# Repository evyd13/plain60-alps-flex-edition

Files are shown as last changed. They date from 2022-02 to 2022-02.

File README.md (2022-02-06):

# Plain60 Alps Flex Edition rev2.2

Plain60 Alps Flex Edition PCB
This 60% alps PCB is designed to support as little layouts as possible without limiting usability for most users.

It also features a fuse and an ESD protection chip to protect the MCU and other parts of the PCB.

## Features
- Compatible with QMK Firmware and VIA Configurator (if you flash a VIA compatible .hex file)
- Compatible with most universal 60% cases
- USB type-C
- Optional JST header for connection with daughterboard
- Footprint for optional speaker (AST1109MLTRQ)
- ESD protection and fuse
- No LEDs and no underglow
- Minimal layout support
- ISP header

## Supported layouts
Supported layouts of the Plain60 Alps Flex Edition

## Building
If you feel like building a few of these PCBs yourself, go to the 'Releases' tab and download the latest gerber files. Order those at your favourite PCB manufacturer, get the components needed (see below) and solder them on! A hot air station is not required but a soldering iron is. Flux is recommended.

## Opening the project
To open the files you will need the latest KiCAD stable (at least 6.0.1) version.

## Bill of materials (BOM)
Amount is per PCB, multiply as needed.

| LCSC part # | Description | Value | Package  | Amount |
| --- | --- | ----- | --- | ---:|
| C128353 | Capacitor | 0.1uF | 0805 | 4 |
| C131056 | Capacitor | 4.7uF | 0805 | 1 |
| C215803 | Capacitor | 1uF | 0805 | 1 |
| C109001 | Diode | | 0805 | 65 |
| C261942 | Fuse | | 0805 | 1 |
| C165948 | Connector | | SMD/THT  | 1 |
| C103904 | Resistor | 10K | 0805 | 2 |
| C212411 | Resistor | 5.1K  | 0805 | 2 |
| C325772 | Resistor | 22 | 0805 | 2 |
| C44854 | MCU | 32U4  | QFP-44 | 1 |
| C7519 | ESD chip | | SOT23-6  | 1 |
| C341521 | Resonator | 16MHz | SMD | 1 |
| C92584 | Switch | | SMD | 1 |
| C160404 | Optional JST  | | SMD | 1 |

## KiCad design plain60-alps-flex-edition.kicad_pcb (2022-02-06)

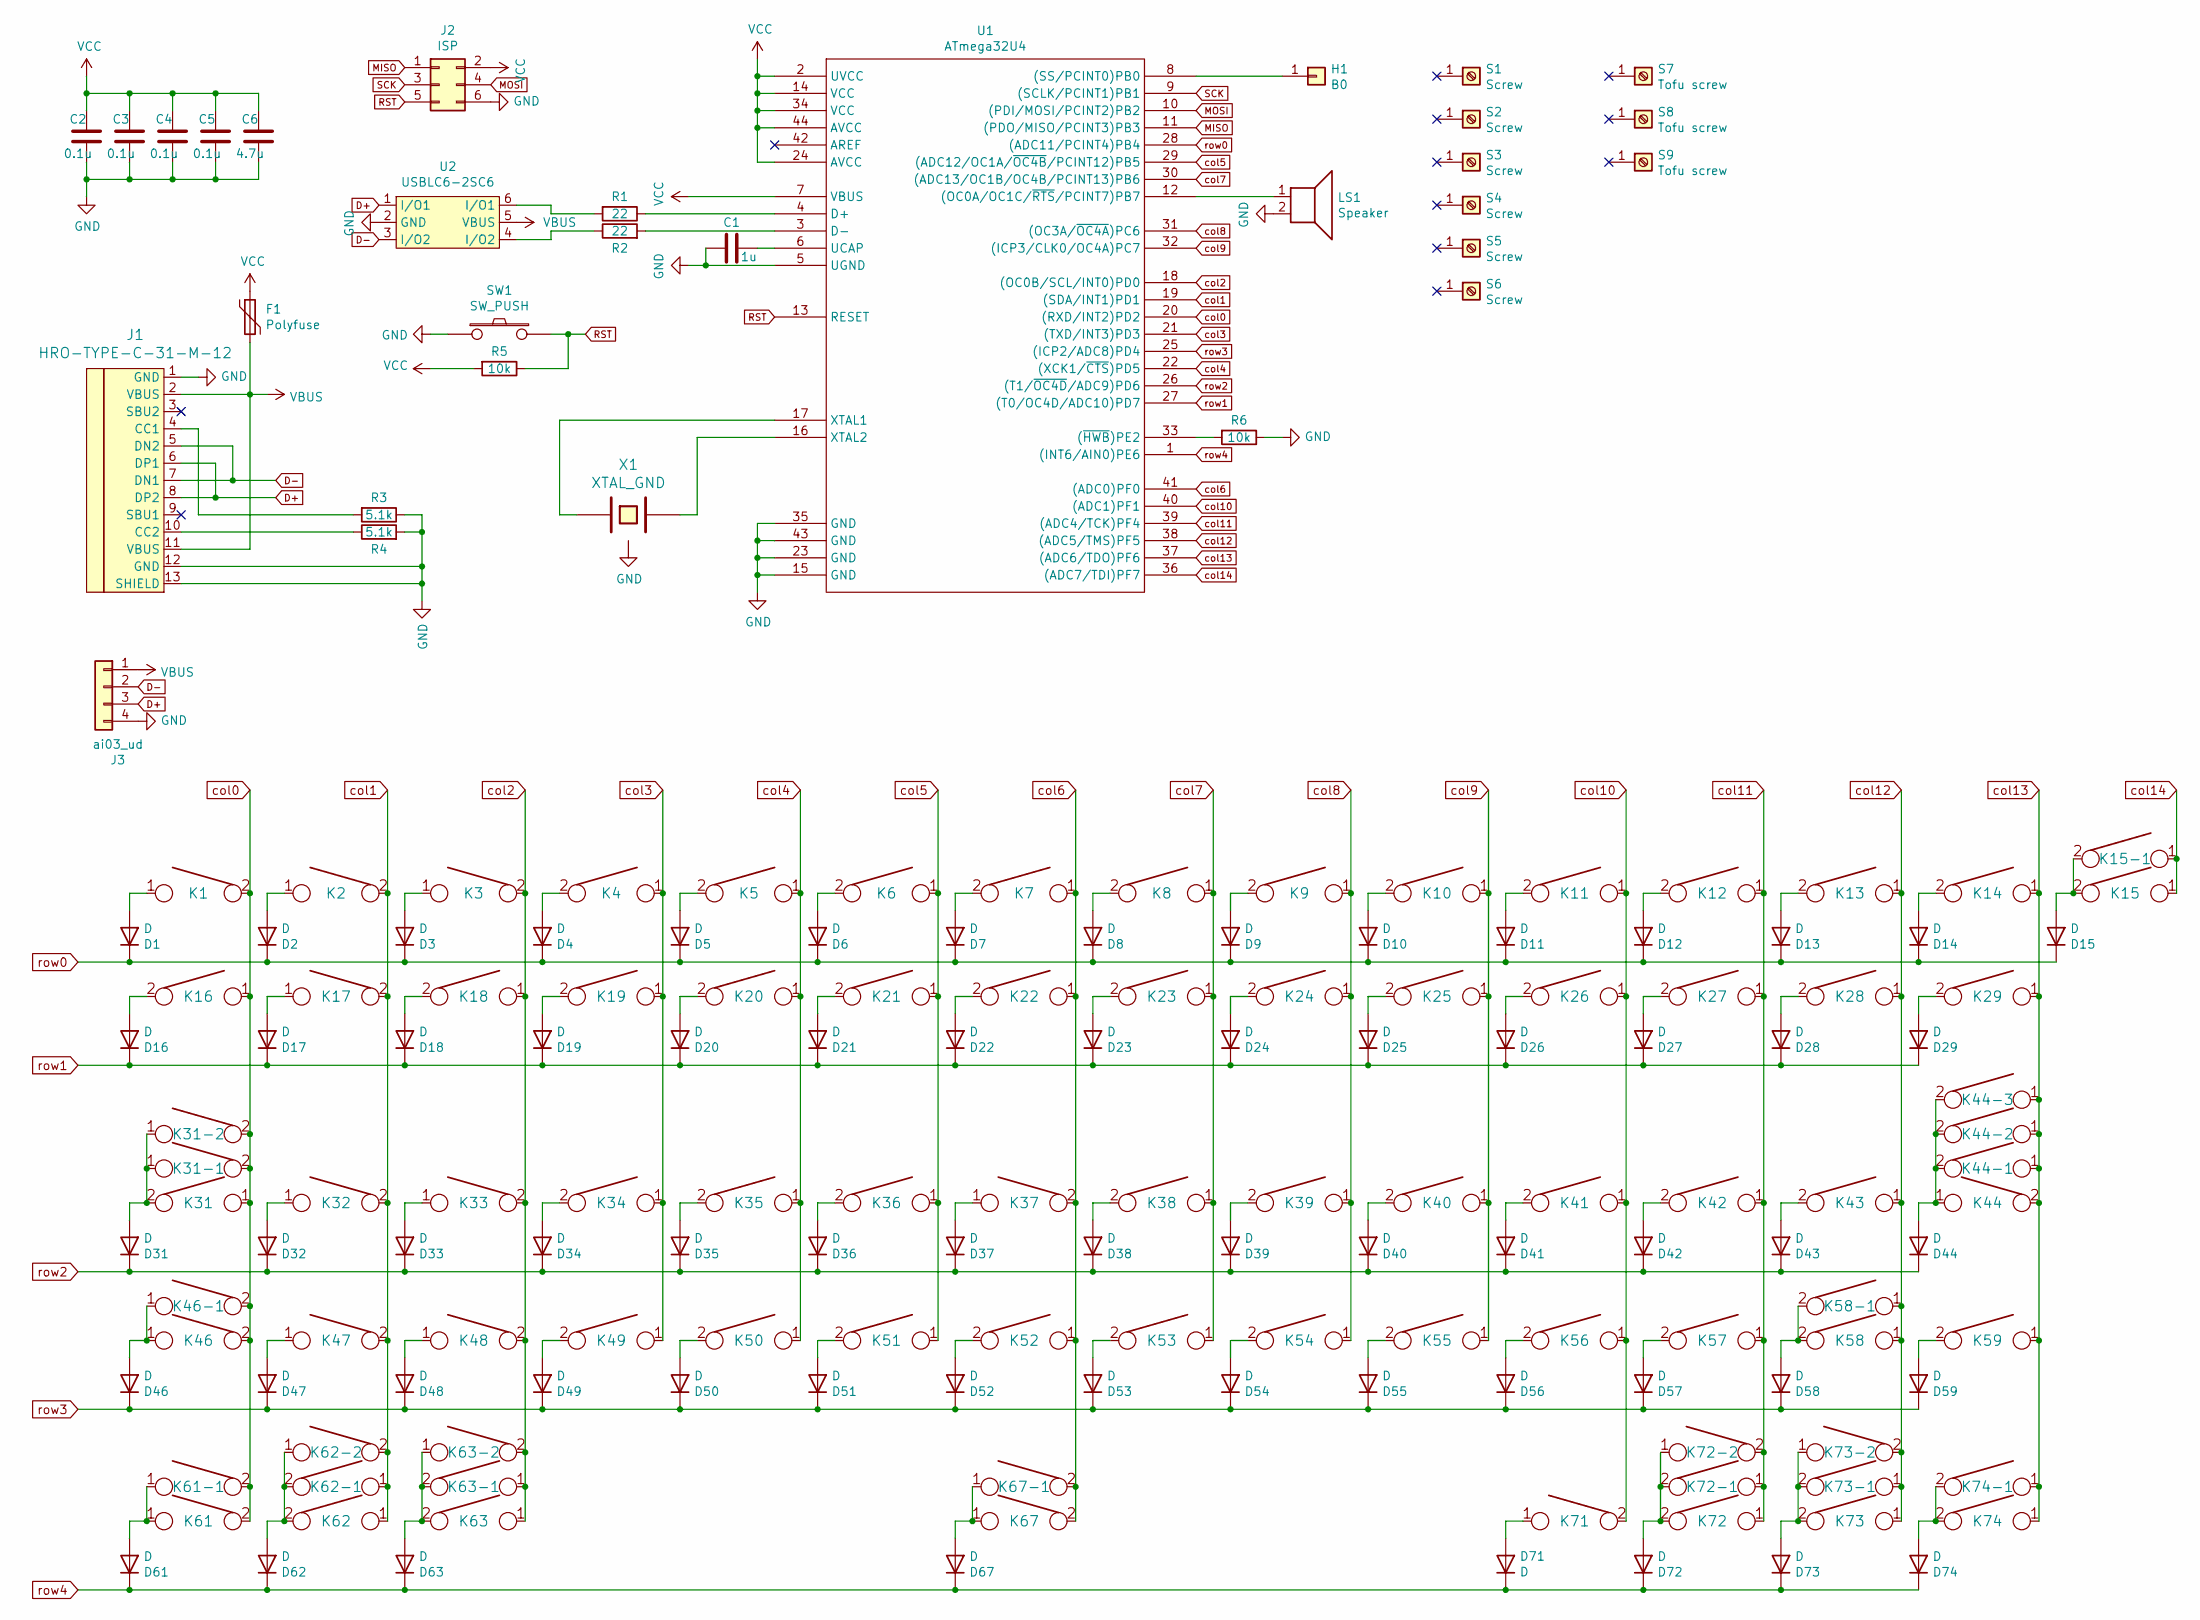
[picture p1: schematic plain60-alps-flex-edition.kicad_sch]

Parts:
C1: 1u; C_0805
C2, C3, C4, C5: 0.1u; C_0805
C6: 4.7u; C_0805
D1, D2, D3, D4, D5, D6, D7, D8, D9, D10, D11, D12, D13, D14, D15, D16, D17, D18, D19, D20, D21, D22, D23, D24, D25, D26, D27, D28, D29, D31, D32, D33, D34, D35, D36, D37, D38, D39, D40, D41, D42, D43, D44, D46, D47, D48, D49, D50, D51, D52, D53, D54, D55, D56, D57, D58, D59, D61, D62, D63, D67, D71, D72, D73, D74: D; D_0805
F1: Polyfuse; R_0805
H1: B0; free_pin
J1: HRO-TYPE-C-31-M-12
J2: ISP; isp_standard
J3: ai03_ud; JST_SH_SM04B-SRSS-TB_1x04-1MP_P1.00mm_Horizontal
K1, K2, K3, K4, K5, K6, K7, K8, K9, K10, K11, K12, K13, K14, K15-1, K17, K18, K19, K20, K21, K22, K23, K24, K25, K26, K27, K28, K32, K33, K34, K35, K36, K37, K38, K39, K40, K41, K42, K43, K47, K48, K49, K50, K51, K52, K53, K54, K55, K56, K57, K59, K62-1, K73-1: KEYSW; ALPS_PLATE_100H
K15: KEYSW; ALPS_PCB_200H
K16, K29, K31-2, K61-1, K63-1, K63-2, K72-1, K72-2, K74-1: KEYSW; ALPS_PLATE_150H
K31, K58-1: KEYSW; ALPS_PLATE_175H
K31-1, K46-1, K61, K62, K62-2, K63, K71, K72, K73, K73-2, K74: KEYSW; ALPS_PLATE_125H
K44, K46: KEYSW; ALPS_PCB_225H
K44-1: KEYSW; ALPS_PCB_200H_F
K44-2, K44-3: KEYSW; ALPS_PLATE_200H
K58: KEYSW; ALPS_PCB_275H
K67: KEYSW; ALPS_PCB_625H_F
K67-1: KEYSW; ALPS_PCB_700H_F
LS1: Speaker; speaker_AST1109MLTRQ
R1, R2: 22; R_0805
R3, R4: 5.1k; R_0805
R5, R6: 10k; R_0805
S1, S2, S3, S6: Screw; 5.5_5x2.5mm
S4, S5: Screw; 10x5_7x2.5mm
S7, S8, S9: Tofu screw; 5.5_5x2.5mm
SW1: SW_PUSH; SW_SPST_TL3342
U1: ATmega32U4; ATMEGA32U4
U2: USBLC6-2SC6; Farnell 1295310
X1: XTAL_GND; Resonator_SMD_muRata_CSTNExxV-3Pin-p1.2

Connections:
D+: J1.6 (DP1), J1.8 (DP2), J3.3, U2.1 (I/O1)
D-: J1.5 (DN2), J1.7 (DN1), J3.2, U2.3 (I/O2)
GND: C1.2, C2.1, C3.1, C4.1, C5.1, C6.1, J1.1 (GND), J1.12 (GND), J1.13 (SHIELD), J2.6, J3.4, LS1.2, R3.1, R4.2, R6.1, SW1.1, U1.5 (UGND), U1.15 (GND), U1.23 (GND), U1.35 (GND), U1.43 (GND), U2.2 (GND), X1.3
MISO: J2.1, U1.11 ((PDO/MISO/PCINT3)PB3)
MOSI: J2.4, U1.10 ((PDI/MOSI/PCINT2)PB2)
unnamed: C1.1, U1.6 (UCAP)
unnamed: D1.2 (A), K1.1
unnamed: D2.2 (A), K2.1
unnamed: D3.2 (A), K3.1
unnamed: D4.2 (A), K4.2
unnamed: D5.2 (A), K5.2
unnamed: D6.2 (A), K6.2
unnamed: D7.2 (A), K7.2
unnamed: D8.2 (A), K8.2
unnamed: D9.2 (A), K9.2
unnamed: D10.2 (A), K10.2
unnamed: D11.2 (A), K11.2
unnamed: D12.2 (A), K12.2
unnamed: D13.2 (A), K13.2
unnamed: D14.2 (A), K14.2
unnamed: D15.2 (A), K15.2, K15-1.2
unnamed: D16.2 (A), K16.2
unnamed: D17.2 (A), K17.1
unnamed: D18.2 (A), K18.2
unnamed: D19.2 (A), K19.2
unnamed: D20.2 (A), K20.2
unnamed: D21.2 (A), K21.2
unnamed: D22.2 (A), K22.2
unnamed: D23.2 (A), K23.2
unnamed: D24.2 (A), K24.2
unnamed: D25.2 (A), K25.2
unnamed: D26.2 (A), K26.2
unnamed: D27.2 (A), K27.2
unnamed: D28.2 (A), K28.2
unnamed: D29.2 (A), K29.2
unnamed: D31.2 (A), K31.2, K31-1.1, K31-2.1
unnamed: D32.2 (A), K32.1
unnamed: D33.2 (A), K33.1
unnamed: D34.2 (A), K34.2
unnamed: D35.2 (A), K35.2
unnamed: D36.2 (A), K36.2
unnamed: D37.2 (A), K37.1
unnamed: D38.2 (A), K38.2
unnamed: D39.2 (A), K39.2
unnamed: D40.2 (A), K40.2
unnamed: D41.2 (A), K41.2
unnamed: D42.2 (A), K42.2
unnamed: D43.2 (A), K43.2
unnamed: D44.2 (A), K44.1, K44-1.2, K44-2.2, K44-3.2
unnamed: D46.2 (A), K46.1, K46-1.1
unnamed: D47.2 (A), K47.1
unnamed: D48.2 (A), K48.1
unnamed: D49.2 (A), K49.2
unnamed: D50.2 (A), K50.2
unnamed: D51.2 (A), K51.2
unnamed: D52.2 (A), K52.2
unnamed: D53.2 (A), K53.2
unnamed: D54.2 (A), K54.2
unnamed: D55.2 (A), K55.2
unnamed: D56.2 (A), K56.2
unnamed: D57.2 (A), K57.2
unnamed: D58.2 (A), K58.2, K58-1.2
unnamed: D59.2 (A), K59.2
unnamed: D61.2 (A), K61.1, K61-1.1
unnamed: D62.2 (A), K62.2, K62-1.2, K62-2.1
unnamed: D63.2 (A), K63.2, K63-1.2, K63-2.1
unnamed: D67.2 (A), K67.1, K67-1.1
unnamed: D71.2 (A), K71.1
unnamed: D72.2 (A), K72.2, K72-1.2, K72-2.1
unnamed: D73.2 (A), K73.2, K73-1.2, K73-2.1
unnamed: D74.2 (A), K74.2, K74-1.2
unnamed: H1.1, U1.8 ((SS/PCINT0)PB0)
unnamed: J1.4 (CC1), R3.2
unnamed: J1.10 (CC2), R4.1
unnamed: LS1.1, U1.12 ((OC0A/OC1C/~RTS/PCINT7)PB7)
unnamed: R1.1, U1.4 (D+)
unnamed: R1.2, U2.6 (I/O1)
unnamed: R2.1, U2.4 (I/O2)
unnamed: R2.2, U1.3 (D-)
unnamed: R6.2, U1.33 ((~HWB)PE2)
unnamed: U1.16 (XTAL2), X1.2
unnamed: U1.17 (XTAL1), X1.1
RST: J2.5, R5.1, SW1.2, U1.13 (RESET)
SCK: J2.3, U1.9 ((SCLK/PCINT1)PB1)
VBUS: F1.2, J1.2 (VBUS), J1.11 (VBUS), J3.1, U2.5 (VBUS)
VCC: C2.2, C3.2, C4.2, C5.2, C6.2, F1.1, J2.2, R5.2, U1.2 (UVCC), U1.7 (VBUS), U1.14 (VCC), U1.24 (AVCC), U1.34 (VCC), U1.44 (AVCC)
col0: K1.2, K16.1, K31.1, K31-1.2, K31-2.2, K46.2, K46-1.2, K61.2, K61-1.2, U1.20 ((RXD/INT2)PD2)
col1: K2.2, K17.2, K32.2, K47.2, K62.1, K62-1.1, K62-2.2, U1.19 ((SDA/INT1)PD1)
col2: K3.2, K18.1, K33.2, K48.2, K63.1, K63-1.1, K63-2.2, U1.18 ((OC0B/SCL/INT0)PD0)
col3: K4.1, K19.1, K34.1, K49.1, U1.21 ((TXD/INT3)PD3)
col4: K5.1, K20.1, K35.1, K50.1, U1.22 ((XCK1/~CTS)PD5)
col5: K6.1, K21.1, K36.1, K51.1, U1.29 ((ADC12/OC1A/~OC4B/PCINT12)PB5)
col6: K7.1, K22.1, K37.2, K52.1, K67.2, K67-1.2, U1.41 ((ADC0)PF0)
col7: K8.1, K23.1, K38.1, K53.1, U1.30 ((ADC13/OC1B/OC4B/PCINT13)PB6)
col8: K9.1, K24.1, K39.1, K54.1, U1.31 ((OC3A/~OC4A)PC6)
col9: K10.1, K25.1, K40.1, K55.1, U1.32 ((ICP3/CLK0/OC4A)PC7)
col10: K11.1, K26.1, K41.1, K56.1, K71.2, U1.40 ((ADC1)PF1)
col11: K12.1, K27.1, K42.1, K57.1, K72.1, K72-1.1, K72-2.2, U1.39 ((ADC4/TCK)PF4)
col12: K13.1, K28.1, K43.1, K58.1, K58-1.1, K73.1, K73-1.1, K73-2.2, U1.38 ((ADC5/TMS)PF5)
col13: K14.1, K29.1, K44.2, K44-1.1, K44-2.1, K44-3.1, K59.1, K74.1, K74-1.1, U1.37 ((ADC6/TDO)PF6)
col14: K15.1, K15-1.1, U1.36 ((ADC7/TDI)PF7)
row0: D1.1 (K), D2.1 (K), D3.1 (K), D4.1 (K), D5.1 (K), D6.1 (K), D7.1 (K), D8.1 (K), D9.1 (K), D10.1 (K), D11.1 (K), D12.1 (K), D13.1 (K), D14.1 (K), D15.1 (K), U1.28 ((ADC11/PCINT4)PB4)
row1: D16.1 (K), D17.1 (K), D18.1 (K), D19.1 (K), D20.1 (K), D21.1 (K), D22.1 (K), D23.1 (K), D24.1 (K), D25.1 (K), D26.1 (K), D27.1 (K), D28.1 (K), D29.1 (K), U1.27 ((T0/OC4D/ADC10)PD7)
row2: D31.1 (K), D32.1 (K), D33.1 (K), D34.1 (K), D35.1 (K), D36.1 (K), D37.1 (K), D38.1 (K), D39.1 (K), D40.1 (K), D41.1 (K), D42.1 (K), D43.1 (K), D44.1 (K), U1.26 ((T1/~OC4D/ADC9)PD6)
row3: D46.1 (K), D47.1 (K), D48.1 (K), D49.1 (K), D50.1 (K), D51.1 (K), D52.1 (K), D53.1 (K), D54.1 (K), D55.1 (K), D56.1 (K), D57.1 (K), D58.1 (K), D59.1 (K), U1.25 ((ICP2/ADC8)PD4)
row4: D61.1 (K), D62.1 (K), D63.1 (K), D67.1 (K), D71.1 (K), D72.1 (K), D73.1 (K), D74.1 (K), U1.1 ((INT6/AIN0)PE6)

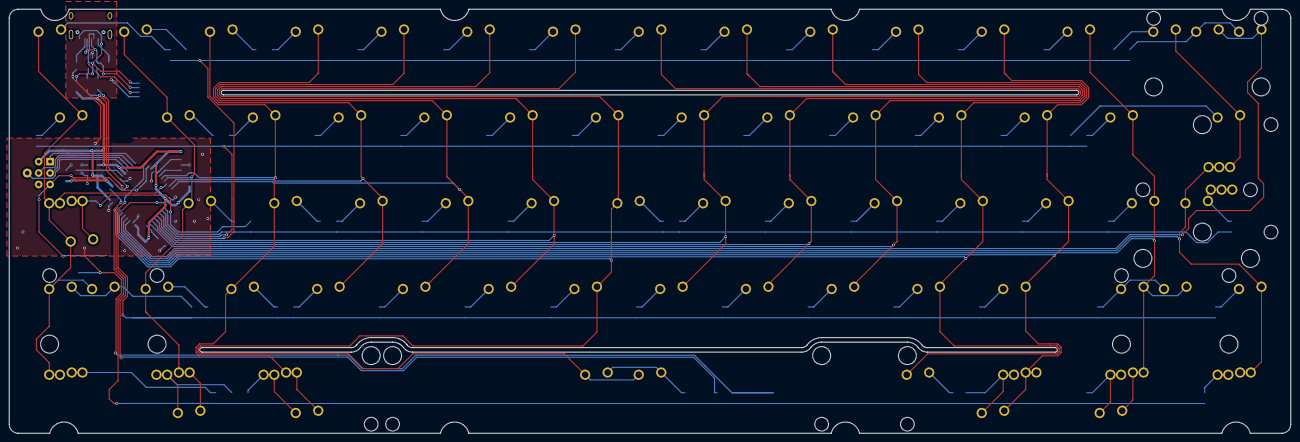
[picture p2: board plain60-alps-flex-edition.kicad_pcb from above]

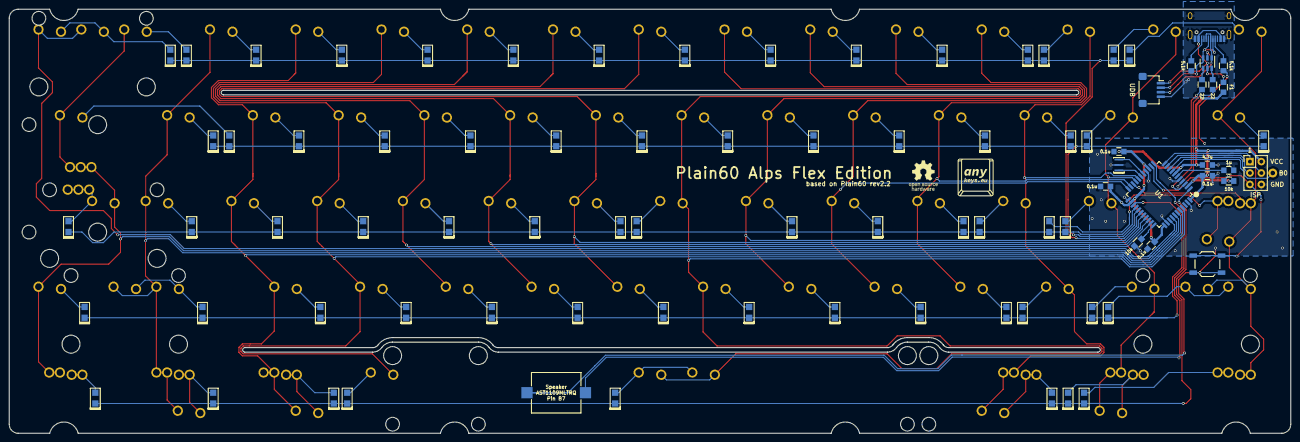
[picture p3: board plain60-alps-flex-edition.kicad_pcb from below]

Board: 2 copper layers, 284.7 x 94.2 mm, 180 parts (87 on the bottom side), 106 nets.
